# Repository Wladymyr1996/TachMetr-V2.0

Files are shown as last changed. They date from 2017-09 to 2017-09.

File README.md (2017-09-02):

# TachMetr-V2.0
The is a LED tachometer for my trike. Work on Atmega8A_AU and MAX7219.

Author: Stadnyk Volodymyr.

Name: TachMetr V2.0.		

License: Free for all.	

KiCad project in folder "Tachmetr V2".

KiCad проект в теці "Tachmetr V2".

KiCad проект в папке "Tachmetr V2".

For compile the firmware for Atmega8, you can run "make".

Для побудови прошивки для Atmega8, Ви можете запустити "make".

Для постройки прошивки для Atmega8, Вы можете запустить "make".

If you have any questions about this project, you can contact with me in Telegram https://t.me/Wladymyr .

Якщо Ви маєте питання щодо цього проекту, Ви можете зв'язатися зі мною в Телеграмі https://t.me/Wladymyr .

Если Вы имеете впоросы по поводу этого проекта, Вы можете свзаться со мной в Телеграме https://t.me/Wladymyr .

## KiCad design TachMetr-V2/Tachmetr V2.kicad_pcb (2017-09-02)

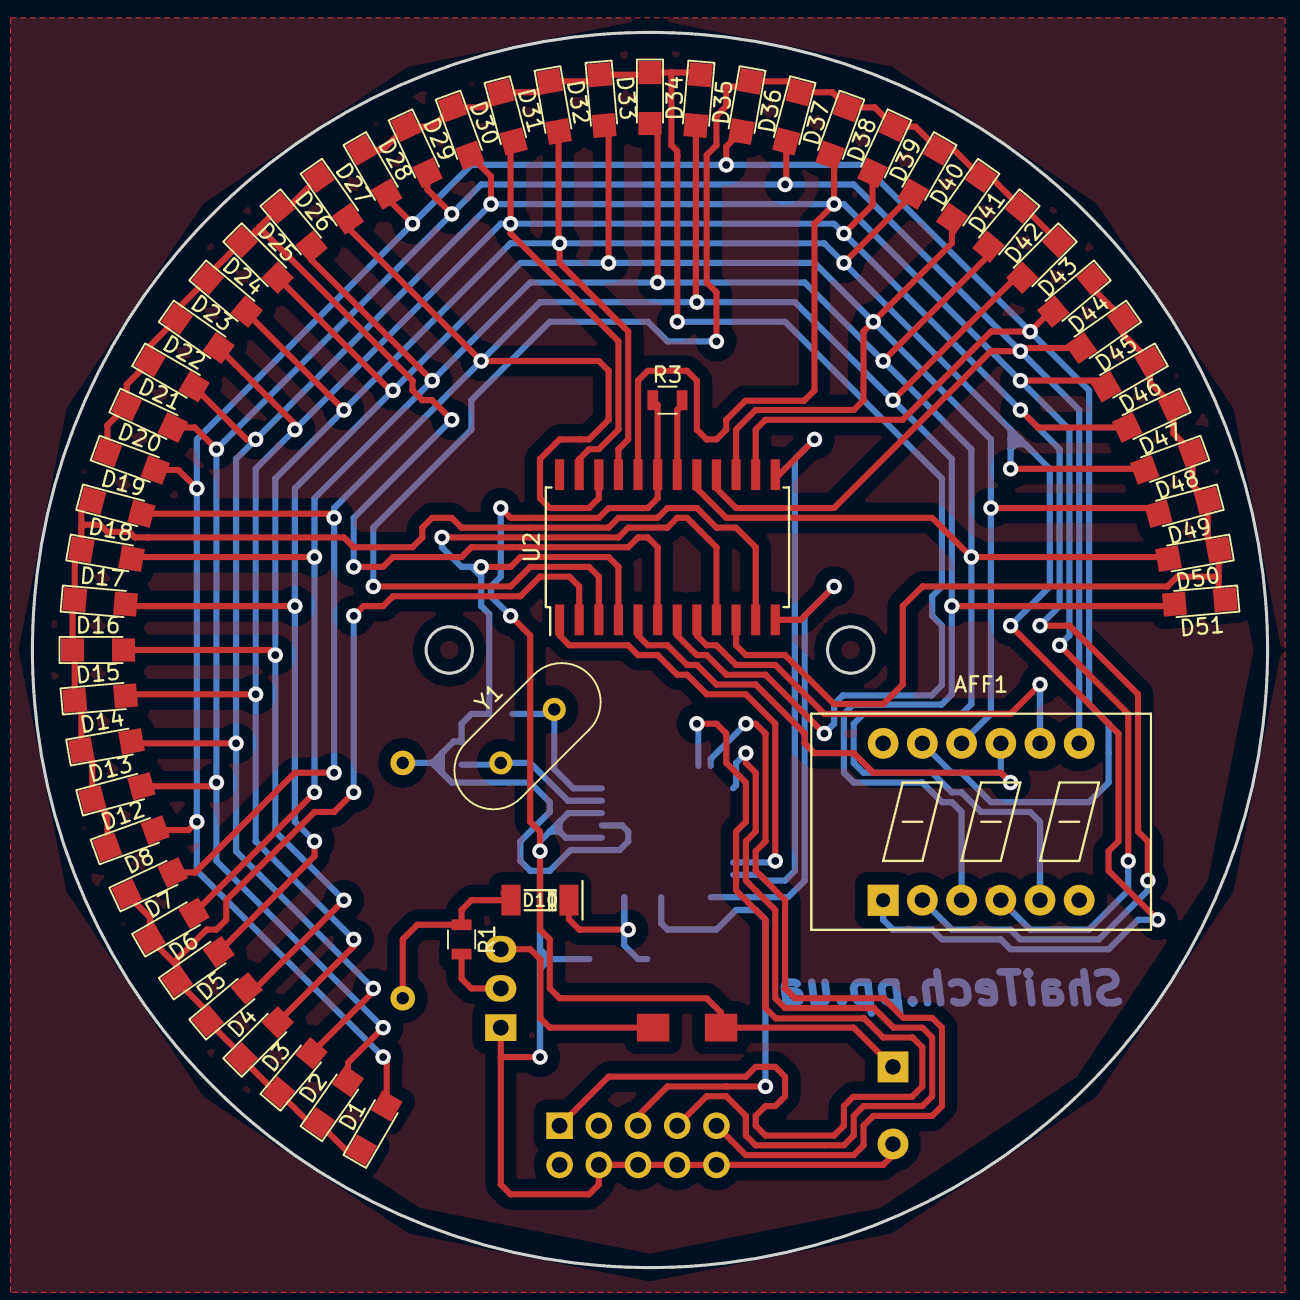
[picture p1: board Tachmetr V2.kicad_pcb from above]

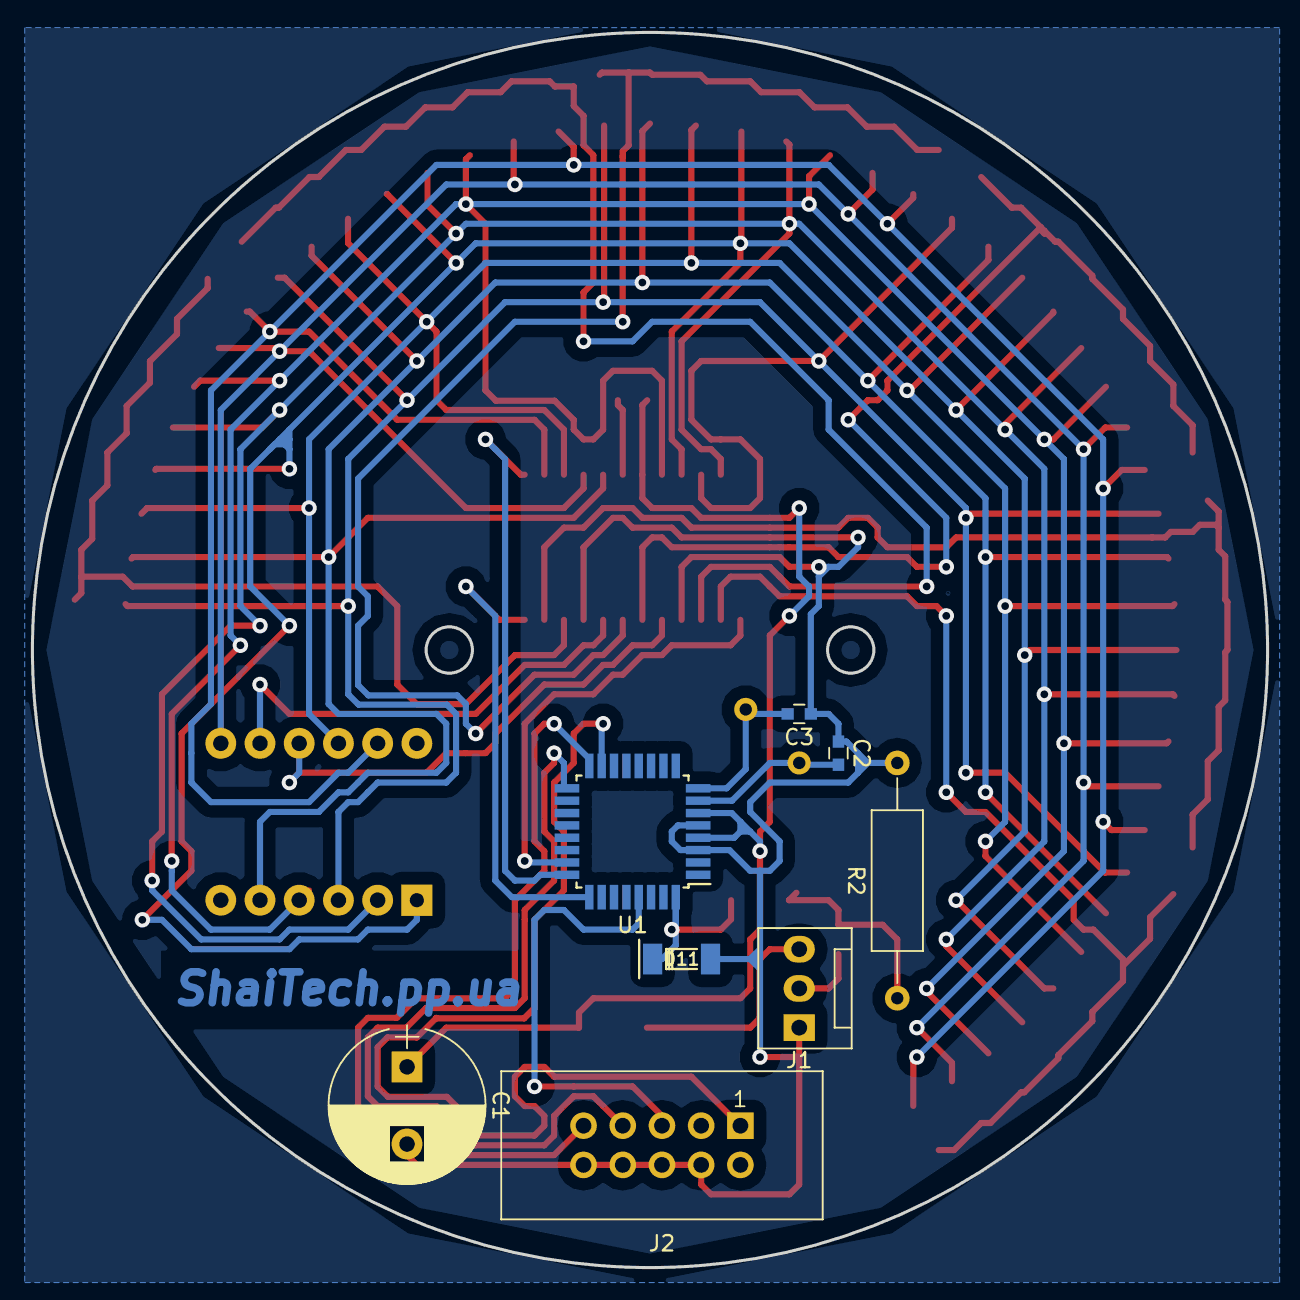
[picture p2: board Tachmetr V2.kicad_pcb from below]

Board: 2 copper layers, 80.0 x 80.0 mm, 63 parts (8 on the bottom side), 32 nets.

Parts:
AFF1: CC56-12; Cx56-12
C1: 1000uF; CP_Radial_D10.0mm_P5.00mm
C2, C3: 22pF; C_0603
D1, D2, D3, D4, D5, D6, D7, D8, D12, D13, D14, D15, D16, D17, D18, D19, D20, D21, D22, D23, D24, D25, D26, D27, D28, D29, D30, D31, D32, D33, D34, D35, D36, D37, D38, D39, D40, D41, D42, D43, D44, D45, D46, D47, D48, D49, D50, D51: LED; LED_1206
D9: M7; DO-214AC
D10: 4148; SOD-80
D11: C5V1; SOD-80
J1: CONN_01X03; Fan_Pin_Header_Straight_1x03
J2: USBASP; IDC_Header_Straight_10pins
R1: 5K1; R_0805
R2: 2K; R_Axial_DIN0309_L9.0mm_D3.2mm_P15.24mm_Horizontal
R3: 10K; R_0805
U1: ATMEGA8A-AU; TQFP-32_7x7mm_Pitch0.8mm
U2: MAX7219; SOIC-24W_7.5x15.4mm_Pitch1.27mm
Y1: 12MHz; Crystal_HC18-U_Vertical

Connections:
+5V: C1.1, D9.1, R3.1, U1.4, U1.6, U2.19
/CLK: U1.24, U2.13
/DATA: U1.23, U2.1
/DIG0: D1.1, D2.1, D3.1, D4.1, D5.1, D6.1, D7.1, D8.1, U2.2
/DIG1: D12.1, D13.1, D14.1, D15.1, D16.1, D17.1, D18.1, D19.1, U2.11
/DIG2: D20.1, D21.1, D22.1, D23.1, D24.1, D25.1, D26.1, D27.1, U2.6
/DIG3: D28.1, D29.1, D30.1, D31.1, D32.1, D33.1, D34.1, D35.1, U2.7
/DIG4: D36.1, D37.1, D38.1, D39.1, D40.1, D41.1, D42.1, D43.1, U2.3
/DIG5: D44.1, D45.1, D46.1, D47.1, D48.1, D49.1, D50.1, D51.1, U2.10
/DIG6: AFF1.9, U2.5
/DIG7: AFF1.8, U2.8
/LOAD: U1.25, U2.12
/SEGA: AFF1.11, D1.2, D12.2, D20.2, D28.2, D36.2, D44.2, U2.14
/SEGB: AFF1.7, D2.2, D13.2, D21.2, D29.2, D37.2, D45.2, U2.16
/SEGC: AFF1.4, D3.2, D14.2, D22.2, D30.2, D38.2, D46.2, U2.20
/SEGD: AFF1.2, D4.2, D15.2, D23.2, D31.2, D39.2, D47.2, U2.23
/SEGDP: AFF1.3, D8.2, D19.2, D27.2, D35.2, D43.2, D51.2, U2.22
/SEGE: AFF1.1, D5.2, D16.2, D24.2, D32.2, D40.2, D48.2, U2.21
/SEGF: AFF1.10, D6.2, D17.2, D25.2, D33.2, D41.2, D49.2, U2.15
/SEGG: AFF1.5, D7.2, D18.2, D26.2, D34.2, D42.2, D50.2, U2.17
GND: C1.2, C2.1, C3.1, D11.2, J1.1, J2.4, J2.6, J2.8, J2.10, R2.2, U1.3, U1.5, U2.4, U2.9
IN: J1.2, R1.2
IN_5V: D10.1, D11.1, U1.32
MISO: J2.9, U1.16
MOSI: J2.1, U1.15
unnamed: C2.2, U1.7, Y1.1
unnamed: C3.2, U1.8, Y1.2
unnamed: D9.2, J1.3
unnamed: D10.2, R1.1, R2.1
unnamed: R3.2, U2.18
RESET: J2.5, U1.29
SCK: J2.7, U1.17

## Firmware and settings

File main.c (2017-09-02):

////////////////////////////////////////////////////////////////////////
////															   	////
////			  Автор: Стадник Володимир Сергійович   			////
////					  Дата: 03.08.2017							////
////					Проект: TachMetr V2.0						////
////		     Посилання: http://shaitech.pp.ua/?p=11             ////
////																////	
////////////////////////////////////////////////////////////////////////

#define F_CPU 12000000UL

//Піни на яких знаходиться шина даних
#define DATA 0
#define CLK 1
#define LOAD 2	

#include <avr/io.h>
#include <avr/interrupt.h>
#include <util/delay.h>

unsigned long long oldRPM=0, RPM=0; //Оберти на хвилину
unsigned long counter=0; //лічильник імпульсів
char rewrite=0, t; //Прапорець "Перемалювати дисплей"

ISR(TIMER1_OVF_vect) {
	oldRPM=RPM; 
	RPM=(counter*155)/100; //Коефіціент 1.55
	counter=0;
	rewrite=1; //Ноновити дані дисплею
	t++;
}

ISR(INT0_vect) {
	counter++;
}

//Надсилання одного байту до мікросхеми
void MAX7219_send_byte(unsigned char data, char direct) {
	char i;
	for (i=0; i<8; i++) {
		//В залежності від направленності бітів, виводимо біт на ногу "DATA"
		if (!direct) PORTC=((data)&0x80)>>(7-DATA); 
		  else PORTC=((data)&0x01)<<(DATA);
		asm("nop"); //Тріхо чекаємо
		PORTC=1<<CLK; //Даємо такт на CLK
		asm("nop");
		PORTC&=~(1<<CLK);
		asm("nop");
		//В залежності від направленності бітів - рухаємо біти в потрібну сторону
		if (!direct) data=data<<1;
		  else data=data>>1;
	}
}

//Надсилання команди до мікросхеми
void MAX7219_send_command(unsigned char adres, unsigned char data, char direct) {
	PORTC&=~(1<<LOAD); //Вмикаємо режим завантаження
	MAX7219_send_byte(adres, 0); //Записуємо адресу в яку будемо писати дані
	MAX7219_send_byte(data, direct); //Передаємо дані
	PORTC|=(1<<LOAD); //Дані передано
}

//Перемалювання дисплею
void MAX7219_repaint(unsigned long long RPM) {
	unsigned long long display;
	unsigned char digit[8];
	char i, tmp;
	display=0x00FFFFFFFFFFFF>>(47-RPM);
	//display=RPM;
	for (i=0; i<6; i++) {
		digit[i]=display>>(i*8);
		
		//Милиці, які можна було прибрати під час проектування плати
		tmp=(digit[i]&0x80)>>7;
		digit[i]<<=1;
		digit[i]|=tmp;
	}
	if (t>12) {
		digit[6]=(RPM/10) | 0x80;
		digit[7]=RPM%10;
		t=0;
	}
	
	for (i=0; i<8; i++) 
		if (i<6) MAX7219_send_command(i+1, digit[i], 1);
		else MAX7219_send_command(i+1, digit[i], 0);
}

int main(void) {
	//Вимикаємо непотріні порти
	DDRB=0x00;
	DDRD=0x00;
	//Вмикаємо тільки необхідні три ноги на обмін даними із MAX7219
	DDRC=0x07;
	
	//Ініціалізація дисплею
	PORTC|=(1<<LOAD);
	MAX7219_send_command(0x0F, 0x00, 0); //Режим тесту - відключений
	MAX7219_send_command(0x0C, 0x01, 0); //Увікнути робоий режим
	MAX7219_send_command(0x0B, 0x07, 0); //Вмикаємо все цифри
	MAX7219_send_command(0x09, 0xC0, 0); //Режим декодування вмикаємо для DIG6 і DIG7
	MAX7219_send_command(0x0A, 0X0A, 0); //Яскравість, яка нам більше подобається
		
	//Налаштування переривань
	//Переривання INT0
	GICR|=(1<<INT0);
	MCUCR|=(1<<ISC01)|(1<<ISC00); //По передньому фронту
	
	//Переривання по таймеру
	TCCR1B=(1<<CS11);
	TIMSK=(1<<TOIE1);
	
	//Анімація включення
	char i;
	for (i=0; i<47; i++) {
		MAX7219_repaint(i);
		_delay_ms(10);
	}
	for (i=47; i>0; i--) {
		MAX7219_repaint(i);
		_delay_ms(50);
	}
	
	sei();		
	while (1) {
		if (rewrite) {
			MAX7219_repaint((oldRPM+RPM)/2); //Малюємо на дисплеї середнє з двох попередніх значень
			rewrite=0;
			sei();
		}
		asm("nop");
	}
}
